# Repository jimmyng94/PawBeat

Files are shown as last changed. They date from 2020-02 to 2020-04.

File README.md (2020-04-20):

# PawPulse
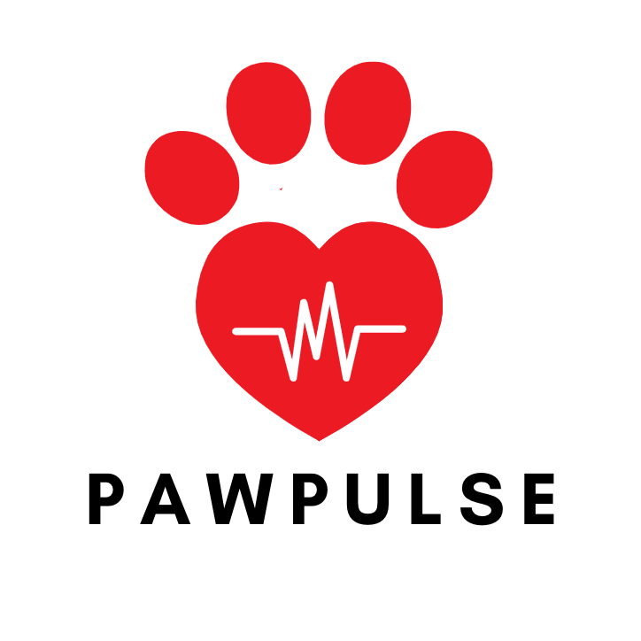
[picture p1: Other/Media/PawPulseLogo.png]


PawPulse is an [open-source](https://github.com/jimmyng94/PawPulse/blob/master/LICENSE) pet health monitoring project developed by Engineering MSc students at the University Of Glasgow using a Raspberry Pi. The main functions that the project provide are:
- Heartbeat Monitoring
- Pedometer
- Live data display through a [website](https://tymonherzyk.github.io/PawPulseWeb/)

Currently, the development of the project is only intended for use on a dog. Usage on other pets will require further testing.

## Project Architecture
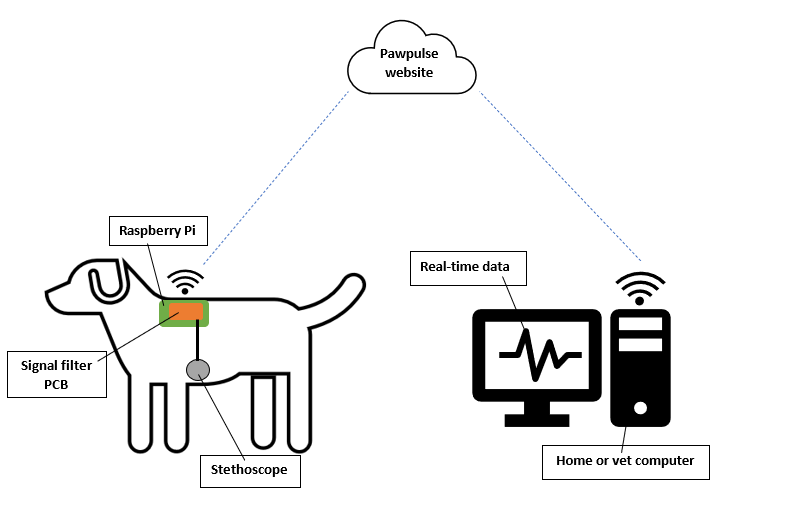
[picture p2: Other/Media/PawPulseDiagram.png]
Basic Design

#### Hardware
All the sensors along with the raspberry will be attached to a dog harness to collect and process the data before posting the data to the web page. Therefore, the PCB is split into 2 individual boards. The 1st board is a PiHat where the [IMU](https://www.st.com/resource/en/datasheet/lsm6ds3.pdf) is located. The 2nd board contains the [ADC](http://www.ti.com/lit/ds/symlink/ads1015.pdf) and is located beside the microphone. Both boards are using I2C to communicate with the Raspberry Pi.

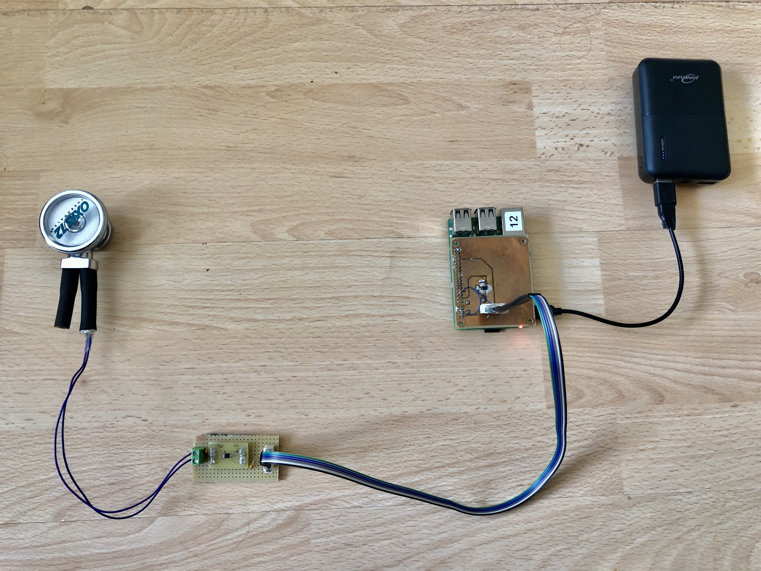
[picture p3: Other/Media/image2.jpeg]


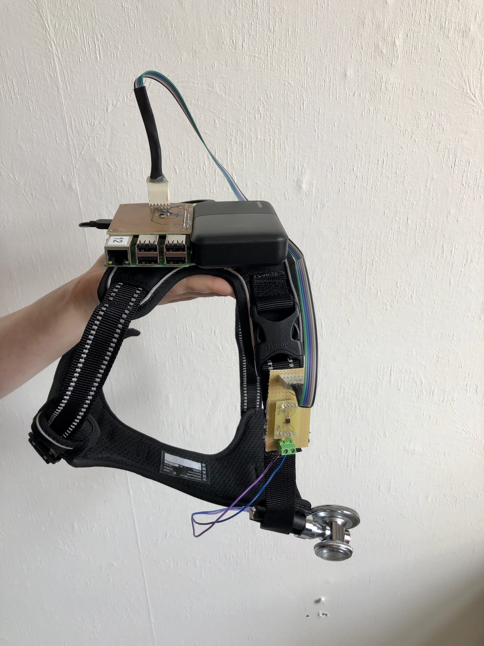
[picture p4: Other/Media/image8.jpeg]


#### Software
The PawPulse software is split into two main files **pawpulse.cpp** and **pawpulseWebClient.cpp**. The pawpulse file is responsible for aquiring data for the dog's heartbeat and step count from the corresponding hardware. Once the data has been aquired through the getBPM() and getStep() functions it is then passed to the writeBPM() and writeSTEP() functions. These functions sort the data into the correct JSON format and pass it to the pawpulseWebClient.cpp file through named pipes bpm_fifo and step_fifo. The pawpulseWebClient file is responsible for uploading the data to the PawPulse website through the PubNub API. Threading has been used throughout the software to allow both processes (bpm and step) to work at the same time.  

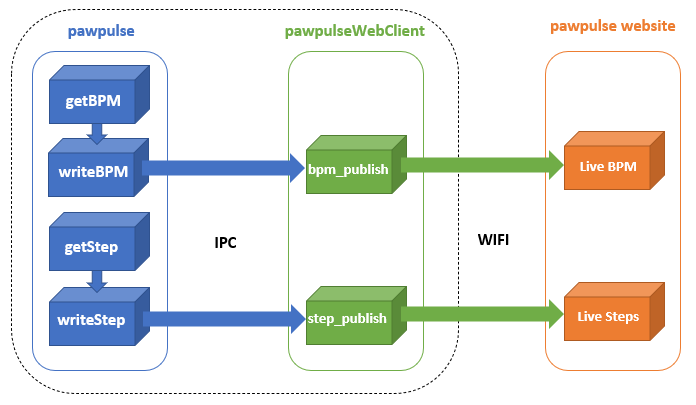
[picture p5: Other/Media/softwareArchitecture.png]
Software Architecture


#### Website
A website has been built in order to test the web capabilities of this project. The website has been designed to function as a profesional space in which the data from the PawPulse system can be displayed to users in real-time. The website has been built using HTML, CSS and JavaScript languages. To display data in real-time it utlises libraries such as PubNub API and EON. The website has also been built to be responsive and hence can be viewed safely on phone and monitors. Example screenshots from the "Live Data" page are given below:

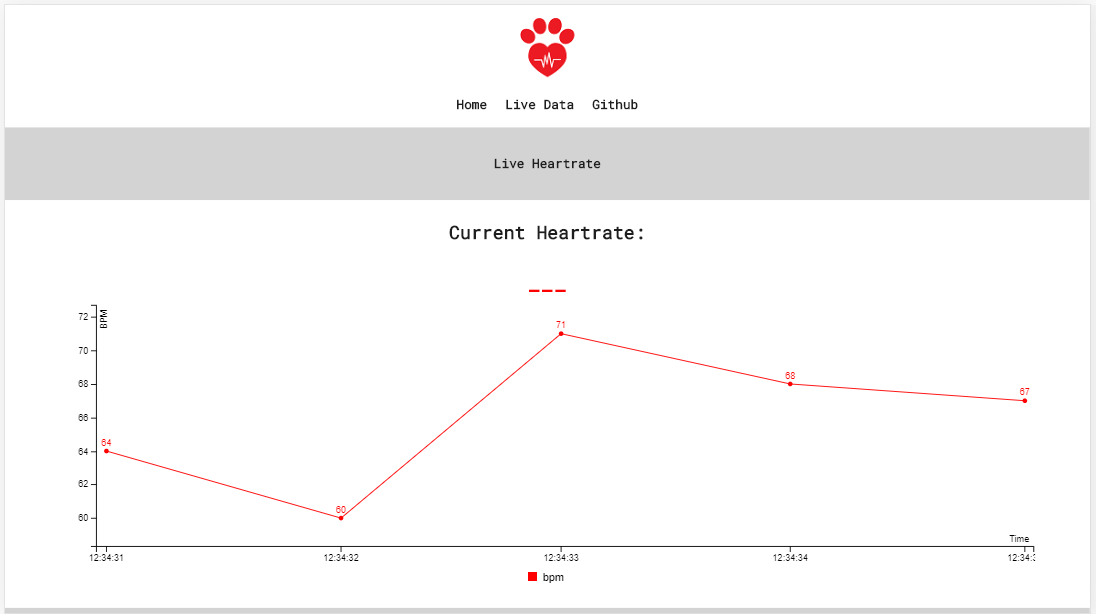
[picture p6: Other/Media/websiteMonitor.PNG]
Web Monitor


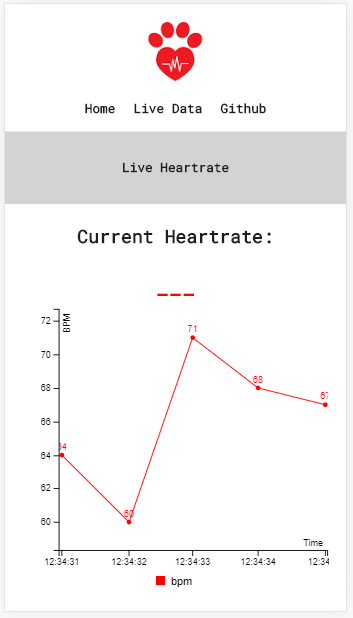
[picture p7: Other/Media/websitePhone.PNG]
Web Phone


The PawPulse website is hosted at https://tymonherzyk.github.io/PawPulseWeb/

#### Guides
Further information as well as in-depth installation and development guides for this project can be found on our Github [Wiki](https://github.com/jimmyng94/PawPulse/wiki) Page.

## Quick Installation
A full in-depth installation guide is available in our [wiki](https://github.com/jimmyng94/PawPulse/wiki/Installation-Guide).

#### 1. Clone PawPulse github repository
On the main repository page, click the green "Clone or Download" button, copy the address that drops down. In your chosen directory clone the PawPulse repository by running the folowing code:
```
git clone *copied address*
```
#### 2. Install required libraries
Install the required libraries (see the wiki for more information):
* ADS1015 Library
* LSM6DS3 Library
* Fir1 Library
* PubNub c-core
* WiringPi

#### 3. Make the pawpulse.cpp executable
To make the pawpulse executable file navigate into the "Software" folder and use the "CMakeLists.txt" file. This is done by running the following code:
```
cmake .
make
```
A new executable with the name **pawpulse** should now be available in the "Software" folder.

#### 4. Make the pawpulseWebClient.cpp executable
To make the pawpulseWebClient executable file navigate into the "Software" folder and use the "pawpulseWebClient.mk" makefile. This is done by running the following code:
```
make -f pawpulseWebClient.mk
```
A new executable with the name **pawpulseWebClient** should now be available in the "Software" folder.

#### 5. Run software
To run both executables simply run the following code in the "Software" folder using two seprate command lines:
```
./pawpulseWebClient
```
```
./pawpulse
```
## Additional Functionality
Recommendations of possible functions that could be added in the future: 
- Automated execution of the PawPulse software.
- Live heartbeat playback allowing the owner to hear their pet's heartbeat and make it more convenient for a veterinarian to monitor pets
- GPS tracking
- Health diagnoses and recommendations
- Personalised website login
- Phone application development for convenience

## Demonstration
A demonstration of the real-time application and operation of the PawPulse software is available on the PawPulse [Youtube Channel](https://www.youtube.com/channel/UC-eADsYPdyjXFOSjoH-YVWg). The demonstration shows the software being executed and the data being uploaded to the PawPulse website in real-time.

Video Link - https://www.youtube.com/watch?v=mI9MpOQwHOM

## Social Media
- [Instagram](https://www.instagram.com/paw_pulse/)
- [Youtube](https://www.youtube.com/channel/UC-eADsYPdyjXFOSjoH-YVWg)
- [Twitter](https://twitter.com/paw_pulse)

## Authors 
- [Maggie Wood](https://github.com/maggwood) - Data acquisition and data filtering
- [Ng Jing Ming](https://github.com/jimmyng94) - Hardware and hardware/software communication
- [Tymon Herzyk](https://github.com/tymonherzyk) - IPC, web client and website

## Disclaimer
Disruption due to COVID-19 has prohibited us from running any actual tests on our test dog. Thus, this project is not guaranteed to work on a dog. Testing was only done using a human heartbeat that was collected before the disruption. In the future we hope to be able to test it on a real pet and collect more data to improve our algorithm. Thank you for your understanding.

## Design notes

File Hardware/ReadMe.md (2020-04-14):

# Hardware
Hardware development of this project went through a few development and testing to determine the best circuit used for this project. 
This project requires an analog to digital converter to convert the analog microphone signal and an inertial measurement unit for pedometer function. 
The selected component used for version 1 of this project is listed below.
The schematic, board design and PCB mask are included in the newest version.  

## Version 0 (Concept)
- Mic signal is passed through a 4th order Low pass filter that filters noise above 1kHz. Used a [LM324N](http://www.ti.com/lit/ds/symlink/lm324-n.pdf). All the components are located in MicBOB_V0. 
- The IMU selected is attached on a PiHat. Fairly straight forward
###### Problems
- The Low pass filter seems to be attenuating the signal and no signal reaches the ADC.
- Missing power line to the VCC of the IMU.

## Version 1 (Prototype A)
- Removed the Low Pass Filter and used the ADS1014 Programmable Gain Amplifier(PGA) to amplify the signal from the microphone.
- Added a diode for reverse voltage protection.
- Added a trace to supply power to the IMU.

| Part | Quantity|
|-----| :-----: |
|Raspberry Pi | 1|
|[ADC ADS1014](http://www.ti.com/lit/ds/symlink/ads1015.pdf)|1|
|[IMU LSM6DS3](https://www.st.com/resource/en/datasheet/lsm6ds3.pdf)|1|
|6mm Microphone|1|
|1206 0.1uf Capacitor |2|
|5K Resistor|4|
|1N4148 Diode|1|
|20-pin Female Header|1|
|6-way header Molex connector|2|
|6-way shell Molex connector|2|
|M2.5 Standoffs	|4|
|M2.5 Screws	|4|

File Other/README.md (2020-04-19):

# Other
This folder contains files that do not fall under the category of hardware or software. 

## Folders
#### Initial Presentation
This folder contains the powerpoint slides used during the initial presentation given at the University of Glasgow on the 29/01/2020.

#### Media
This folder contains all the media files used on the PawPulse github.

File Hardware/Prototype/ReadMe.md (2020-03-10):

# Hardware Development
* After some consideration of device that are suitable for this project there are the ADS1014 is selected and the LSM6DS3 is selected. 
* To test the ADC a breakoutboard (msop10.brd) is develop for quick testing.
* The IMU used for initial testing is purchased from [sparkfun](https://www.sparkfun.com/products/13339)

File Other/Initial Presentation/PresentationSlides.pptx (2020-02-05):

## Development of health monitoring system for dogs (PawPulse)

Team 12
Jing Ming Ng
Margaret Wood
Tymon Herzyk

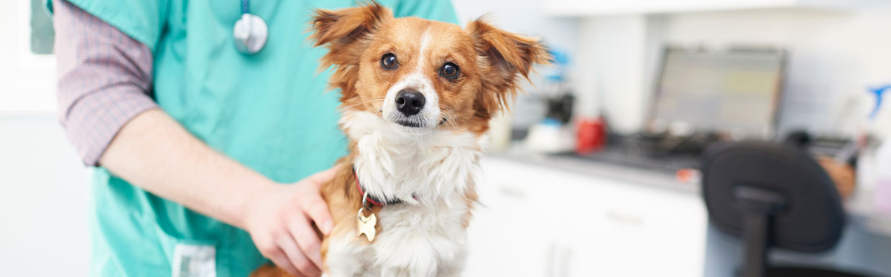
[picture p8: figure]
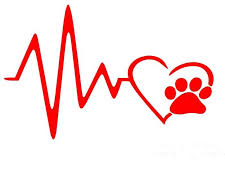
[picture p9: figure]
A picture containing drawing Description generated with very high confidence

## Market & opportunity

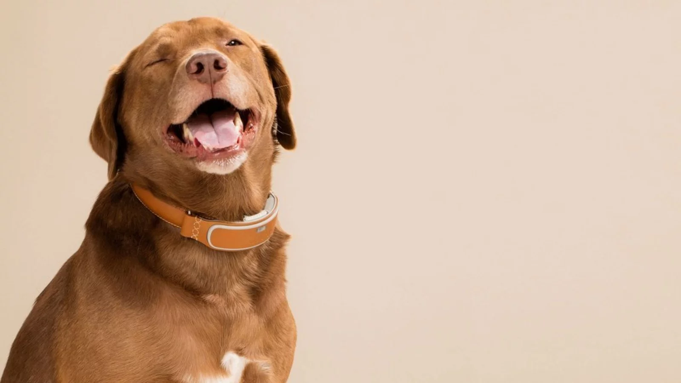
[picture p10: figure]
A brown and white dog looking at the camera Description generated with very high confidence
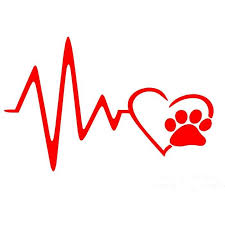
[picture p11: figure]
A picture containing drawing Description generated with very high confidence

Competitors

- Most do trackers do not track heartbeat.
- Trackers with heartbeat have large costs associated.
- Readings are not accurate.
- Low customer reviews.

Innovation

- Inclusion of heartbeat sensing capabilities.
- Low-cost design.
- Ubiquitously available production methods.
- Open-source design

31%
of owners don't know the weight or body condition of their dog (PDSA 2019)

15%
of UK dogs will suffer from a heart condition during their life. (Vet's Kitchen 2020)

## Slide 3

Our Plan

Social Media

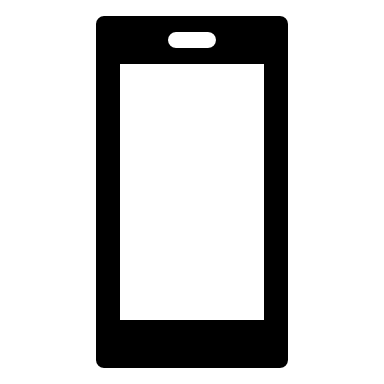
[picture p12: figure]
Smart Phone

Follow @paw_pulse on Twitter and Instagram for #pupdates!

Device

Next Steps

- How heartrate will be measured?
- Total number of features other than heart rate?
- How will device attach to dog?

Hardware Design

- Sensors and Raspberry Pi mounted to wearable apparatus
- Small and compact
- Battery Pack

Real Time Processing

- Intake animal's heartbeat, step count, etc. from sensors
- DSP of sensor signals
- Display useful information thru web page interface
- Data logged for future retrieval

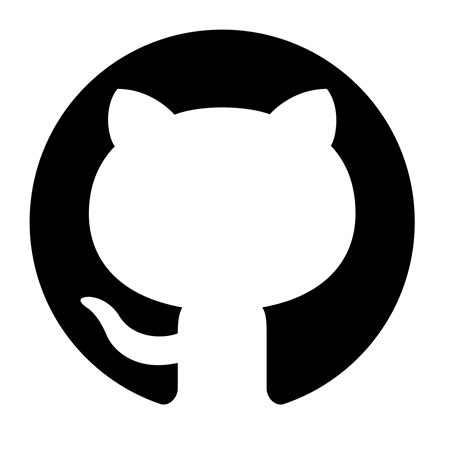
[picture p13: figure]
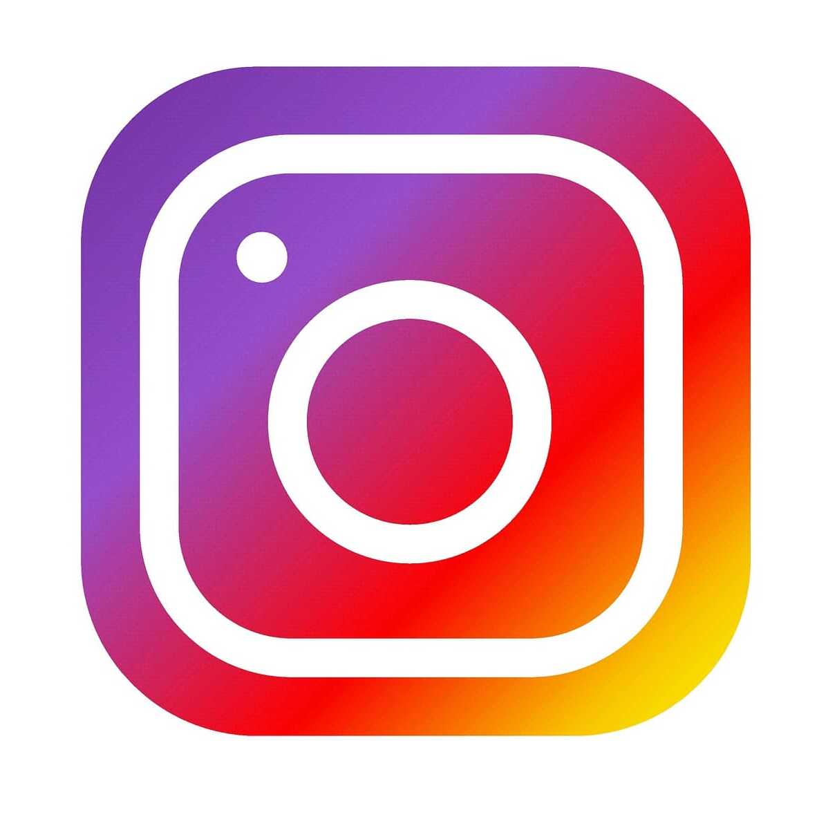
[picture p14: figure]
A picture containing drawing Description generated with very high confidence
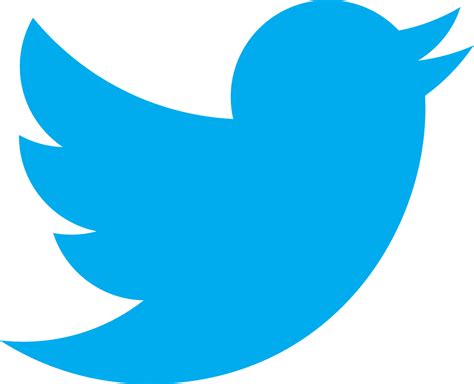
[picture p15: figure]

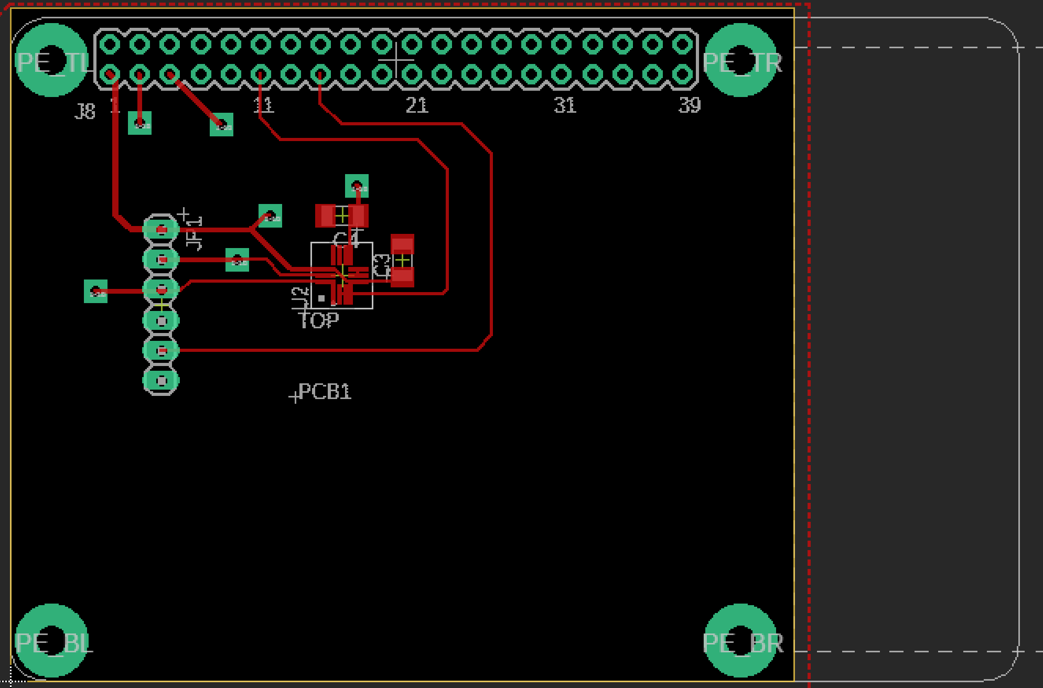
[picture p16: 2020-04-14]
Hardware/V1/piHatV1/pihat.PNG

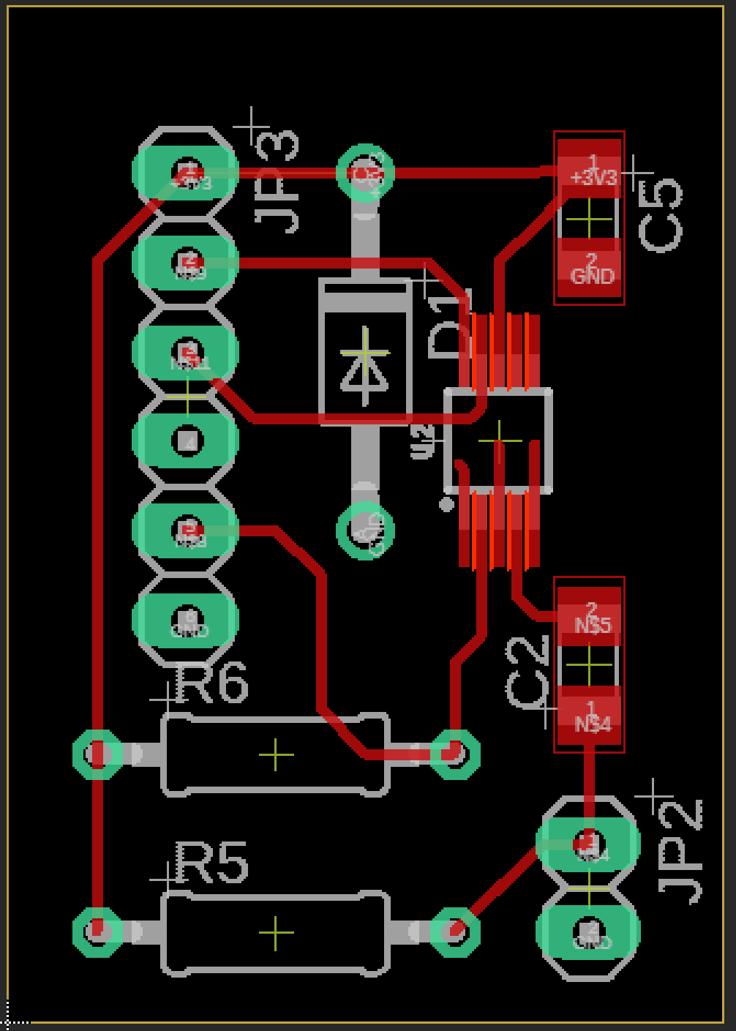
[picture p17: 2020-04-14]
Hardware/V1/mic_bobV1/mic_bobV1.PNG

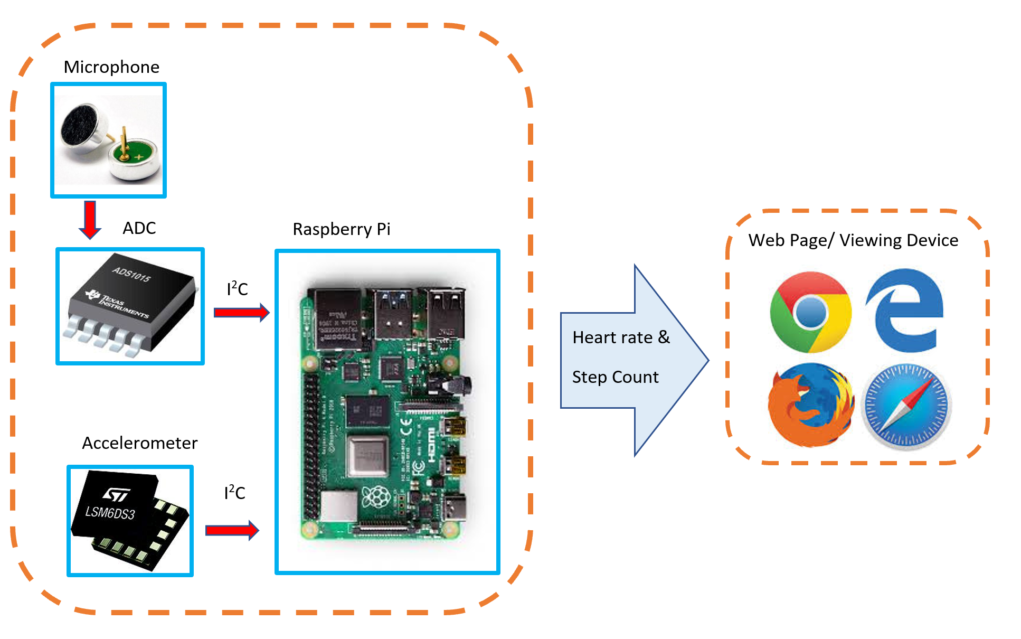
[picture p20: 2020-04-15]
Other/Media/flowDiagram.png

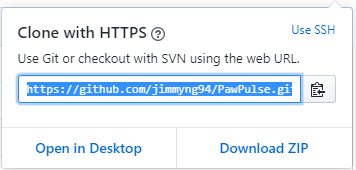
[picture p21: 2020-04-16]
Other/Media/githubLink.PNG

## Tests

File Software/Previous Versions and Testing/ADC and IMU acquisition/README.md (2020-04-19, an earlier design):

# Threaded Data collection With interrupt

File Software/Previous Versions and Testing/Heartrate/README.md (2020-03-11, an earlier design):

# Heart Rate Processing using Microphone output through ADS 1014 

## Requirements
* [WiringPi](http://wiringpi.com/)
* [Fir1 Package](https://github.com/berndporr/fir1)

## Install
```
cmake .
make
sudo make install
sudo ldconfig
```

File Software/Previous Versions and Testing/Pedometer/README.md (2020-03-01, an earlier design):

# LSM6DS3 RaspberryPI C++ Library

## Requirement
* [WiringPi](http://wiringpi.com/)

## Install
```
cmake .
make
sudo make install
sudo ldconfig
```

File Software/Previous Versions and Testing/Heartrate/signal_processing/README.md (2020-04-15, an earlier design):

Run coefficient_generator.py

Run processing.cpp

REQUIRES: Fir1 - Bernd Porr https://github.com/berndporr/fir1, ADS1015, LSM6DS3

What's needed: 

- Add code for sending bpm & step down pipe (not sure if these variables even send from the right place...)              
              
- Not sure of best threshold for bpm conversion with 50 sps - would need new samples in Excel to examine
               
- Not sure of threshold for step - I just made something up. Any way there is some data I could look at?
               
- Not sure which pin ACC interrupts from. Needed for #define statement
               
I have no idea if any of this will work

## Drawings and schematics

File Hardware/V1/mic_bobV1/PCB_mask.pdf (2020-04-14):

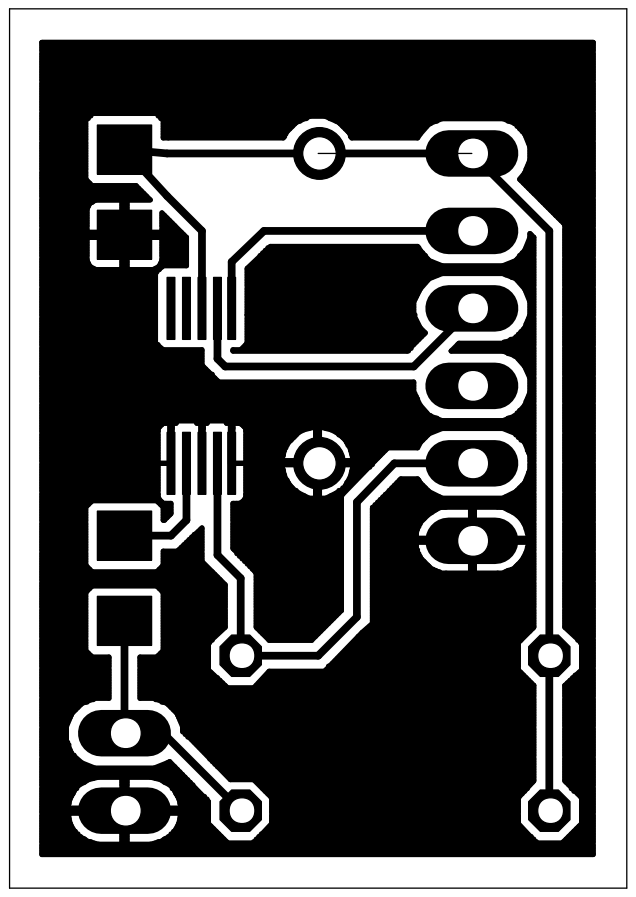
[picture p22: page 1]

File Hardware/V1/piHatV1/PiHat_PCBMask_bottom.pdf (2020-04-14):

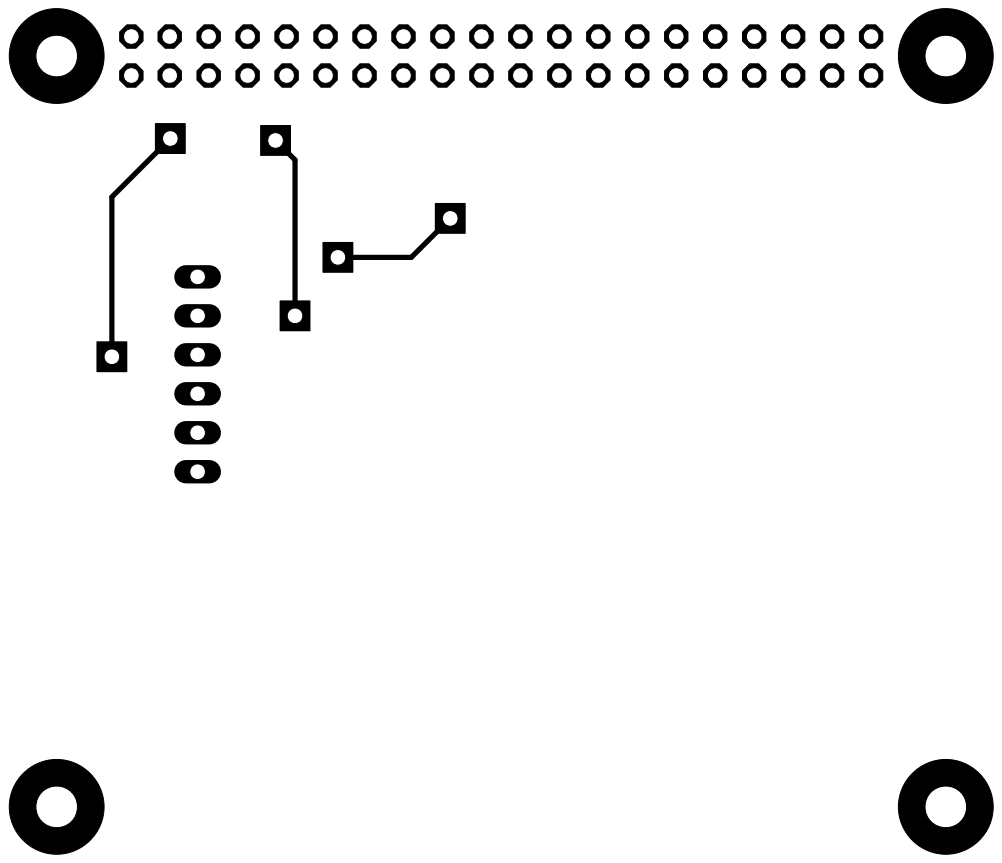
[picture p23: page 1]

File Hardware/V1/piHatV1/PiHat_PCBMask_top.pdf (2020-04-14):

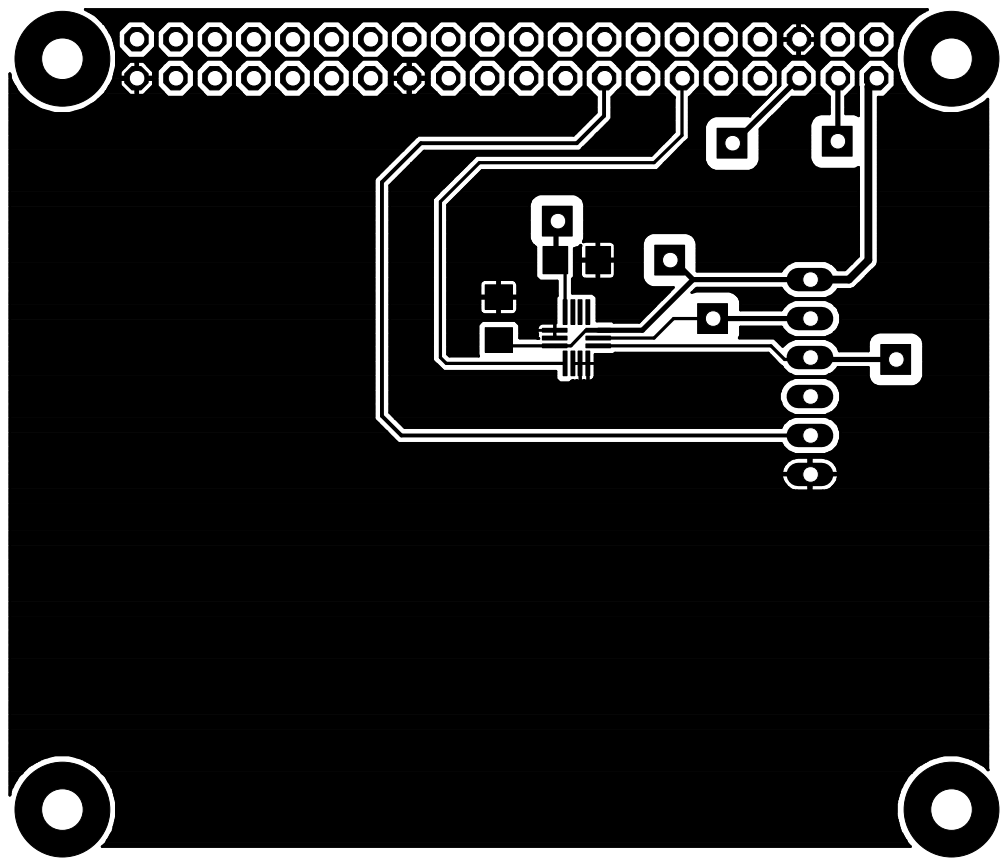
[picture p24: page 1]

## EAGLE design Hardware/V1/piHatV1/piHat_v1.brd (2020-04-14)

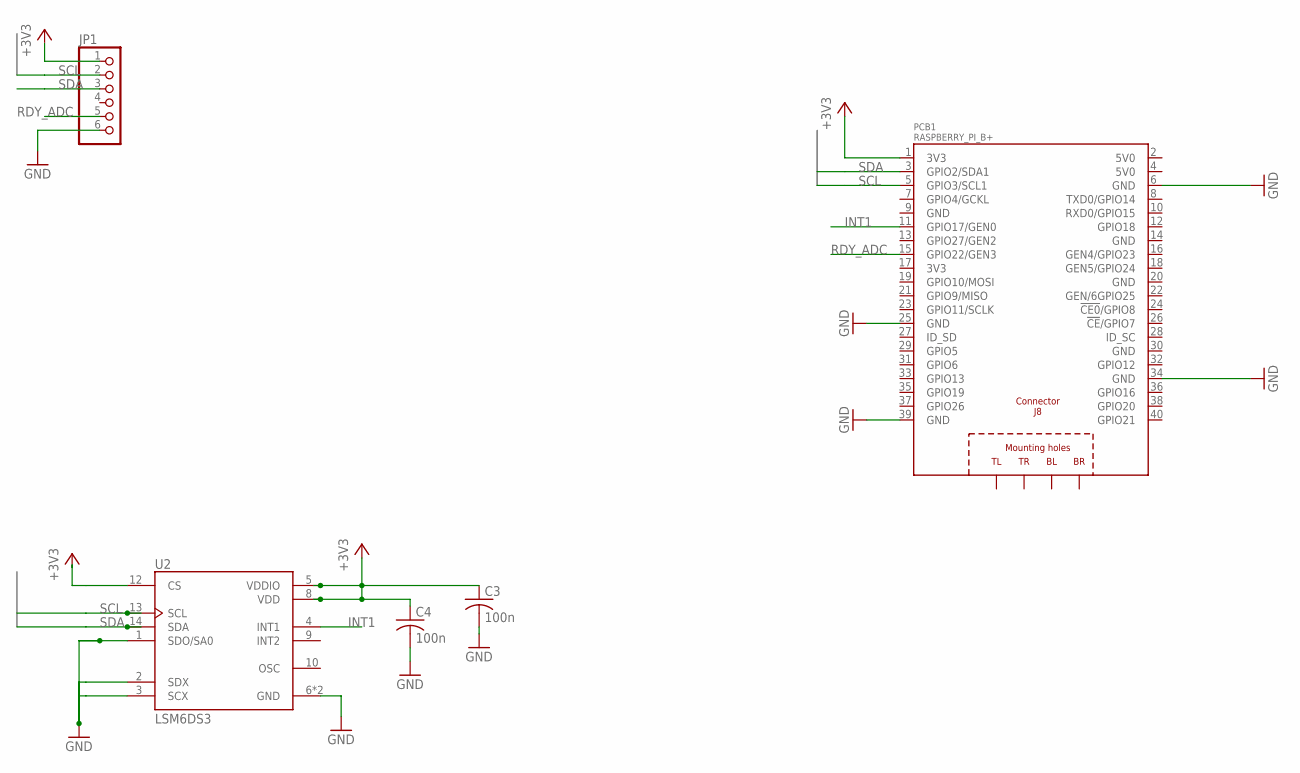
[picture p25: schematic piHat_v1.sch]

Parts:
C3, C4: 100n; C1206
JP1: PINHD-1X6; 1X06
PCB1: RASPBERRY_PI_B+
U2: LSM6DS3; PQFN50P300X250X86-14N

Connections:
+3V3: C3.1, C4.1, JP1.1, PCB1.1 (3V3), U2.5 (VDDIO), U2.8 (VDD), U2.12 (CS)
GND: C3.2, C4.2, JP1.6, PCB1.6 (GND), PCB1.25 (GND), PCB1.39 (GND), U2.1 (SDO/SA0), U2.2 (SDX), U2.3 (SCX), U2.6 (GND), U2.7 (GND)
GND@7: PCB1.34 (GND)
INT1: PCB1.11 (GPIO17/GEN0), U2.4 (INT1)
RDY_ADC: JP1.5, PCB1.15 (GPIO22/GEN3)
SCL: JP1.2, PCB1.5 (GPIO3/SCL1), U2.13 (SCL)
SDA: JP1.3, PCB1.3 (GPIO2/SDA1), U2.14 (SDA)

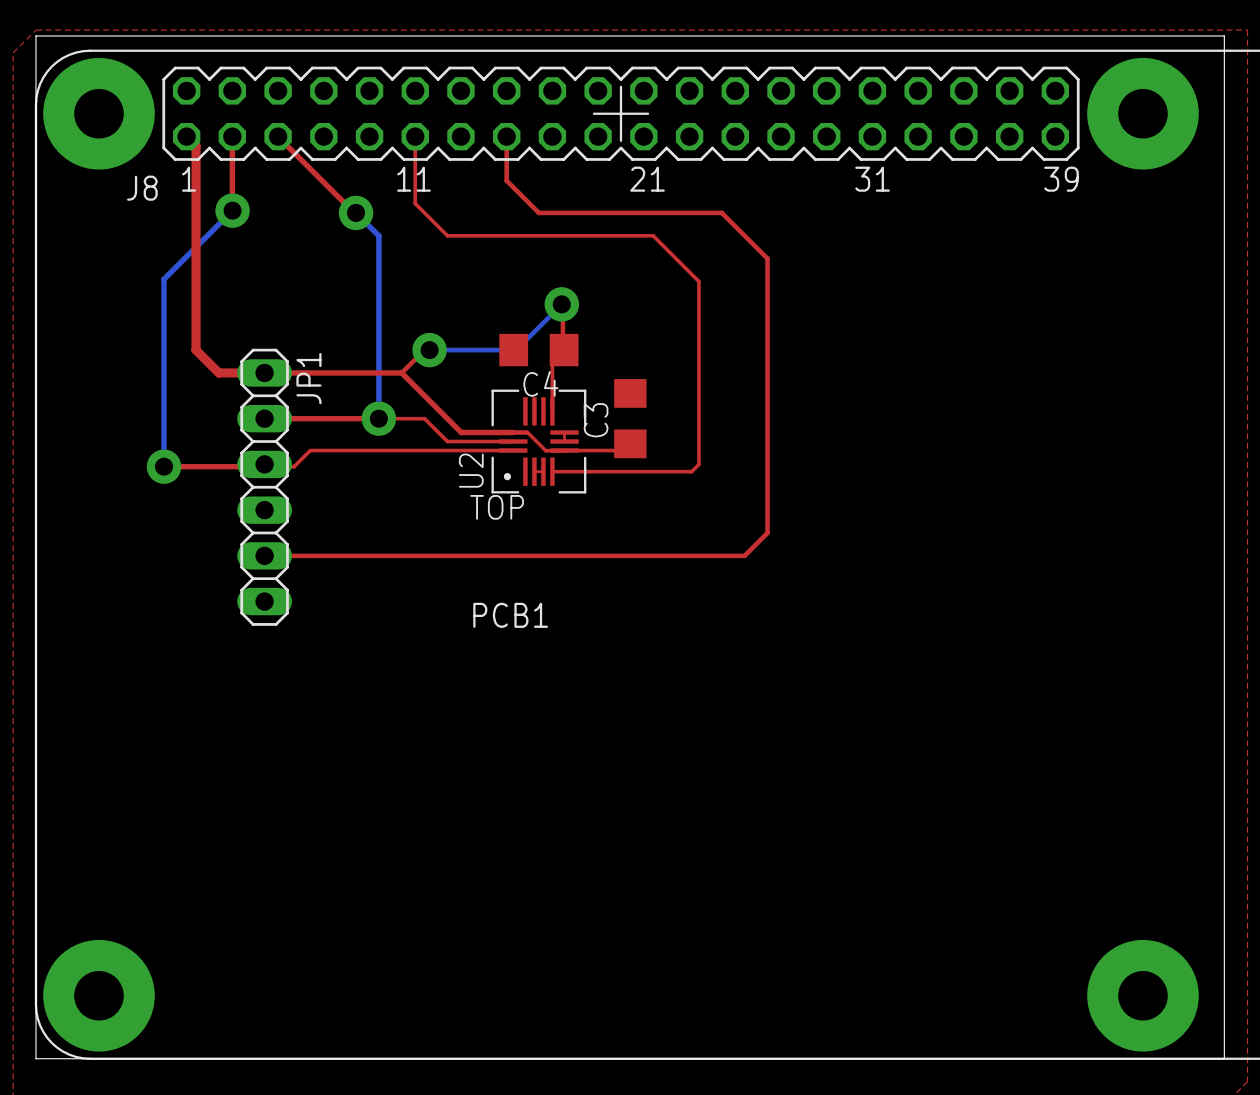
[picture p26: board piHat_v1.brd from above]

Board: 2 copper layers, 66.0 x 56.8 mm, 5 parts (0 on the bottom side), 6 nets.

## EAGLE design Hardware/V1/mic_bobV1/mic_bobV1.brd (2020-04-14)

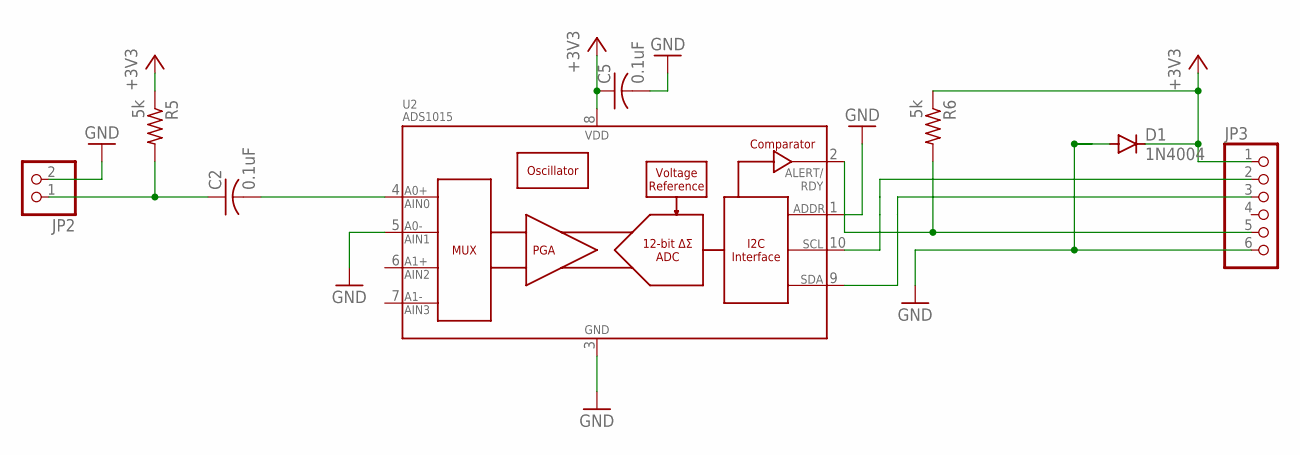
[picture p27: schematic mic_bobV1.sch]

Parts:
C2, C5: 0.1uF; C1206
D1: 1N4004; DO41-10
JP2: PINHD-1X2; 1X02
JP3: PINHD-1X6; 1X06
R5, R6: 5k; 0207/10
U2: ADS1015; MSOP10

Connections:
+3V3: C5.1, D1.C, JP3.1, R5.1, R6.1, U2.8 (VDD)
GND: C5.2, D1.A, JP2.2, JP3.6, U2.1 (ADDR), U2.3 (VSS), U2.5 (AIN1)
unnamed: C2.1, JP2.1, R5.2
unnamed: C2.2, U2.4 (AIN0)
unnamed: JP3.5, R6.2, U2.2 (ALERT/RDY)
unnamed: JP3.2, U2.10 (SCL)
unnamed: JP3.3, U2.9 (SDA)

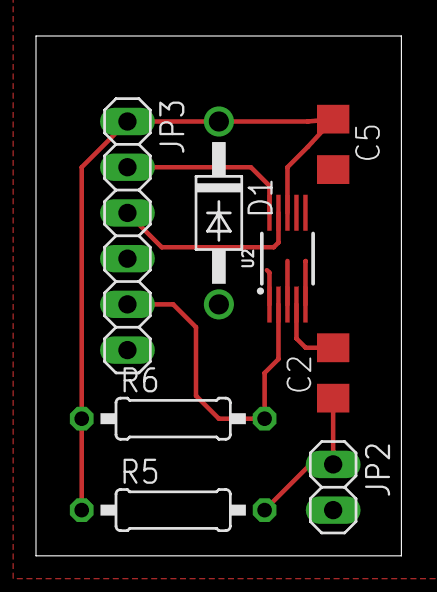
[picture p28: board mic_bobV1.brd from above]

Board: 2 copper layers, 20.3 x 28.9 mm, 8 parts (0 on the bottom side), 7 nets.

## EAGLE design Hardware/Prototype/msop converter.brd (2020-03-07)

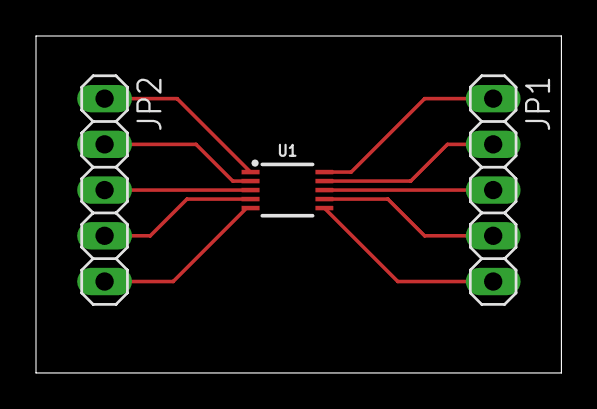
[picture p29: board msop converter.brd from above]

Board: 2 copper layers, 29.2 x 18.7 mm, 3 parts (0 on the bottom side), 10 nets.

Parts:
JP1, JP2: 1X05
U1: ADS1015; MSOP10

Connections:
unnamed: JP2.1, U1.1
unnamed: JP2.2, U1.2
unnamed: JP2.3, U1.3
unnamed: JP2.4, U1.4
unnamed: JP2.5, U1.5
unnamed: JP1.1, U1.10
unnamed: JP1.2, U1.9
unnamed: JP1.3, U1.8
unnamed: JP1.4, U1.7
unnamed: JP1.5, U1.6

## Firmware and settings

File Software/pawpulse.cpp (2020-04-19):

#include <iostream> 
#include <fstream> 
#include <fcntl.h> 
#include <inttypes.h>
#include <linux/i2c-dev.h> 
#include <stdio.h> 
#include <unistd.h> 
#include <stdlib.h> 
#include <sys/types.h> 
#include <sys/stat.h> 
#include <sys/ioctl.h> 
#include <wiringPi.h> 
#include <wiringPiI2C.h> 
#include <errno.h> 
#include <ADS1015.h> 
#include <vector> 
#include <cmath> 
#include <time.h> 
#include "LSM6DS3.h"
#include "Fir1.h"
#include <string.h> 
#include <thread>
#include <sstream>
#define ADC_PIN 3	//input pin for ADC for microphone
#define ACC_PIN 7	//input pin for accelerometer
#define Fs 120		//sampling frequency of ADC

using namespace std; 
bool simulate = true;
static volatile int step = 0;
static volatile int counter = 0; 
static volatile int upflag = 0;
static volatile int stepflag = 0;
static volatile int t = 0;
vector <float> _bpm;
vector <float> _step;
std::vector<int> arr;	//handles simulated adc data
std::vector<float> acc_x;	//handles simulated acc data
std::vector<float> acc_y;
std::vector<float> acc_z;
static volatile bool threadRunning ;

//set up hardware
Adafruit_ADS1015 ads; 
LSM6DS3 imu(I2C_MODE, 0x6A);

//set up fir filter
Fir1 fir("hr_coeff.dat");

void getStep(void){
	float x;
	float y;
	float z;
	
	//if simulate is false, get next available value of x, y, and z from accelerometer
	if(simulate == false){
		x = imu.readFloatAccelX();
		y = imu.readFloatAccelY();
		z = imu.readFloatAccelZ();
	}
	//if simulate is true, get next available value of x, y, and z from pre-recorded data
	else{
		if (acc_x.empty() == false){ 
			x = acc_x.back();
			acc_x.pop_back(); 
			
			y = acc_y.back();
			acc_y.pop_back();
			
			z = acc_z.back();
			acc_z.pop_back();
		}
	}
	//calculate magnitude of x, y, and z to determine if a step has occurred (peak)
	float mag = sqrt(pow(x,2)+pow(y,2)+pow(z,2));
	//if peak occurs, add one to step count
	if(mag > 1.2){
		if(stepflag == 0){
			step++;
			_step.push_back(step);
			cout << "STEP: " << step << endl;
		}
		stepflag  = 5;
	}
	else{
		if(stepflag > 0){
			stepflag--;
		}
	}
	
}//end getStep

void getBPM(void){
	float val;
	//if simulate is false, get next available microphone readout from ADS
	if (simulate == false){ 
		val = ads.getLastConversionResults();  
	}
	//if simulate is true, get next available microphone readout from pre-recorded data
	else
	{	
		if (arr.empty() == false){ 
			val = arr.back();
			arr.pop_back(); 
		}
	}
	//put value through FIR filter to remove noise
	float newVal = fir.filter(val);
	int bpm = 0;
	//square values to remove negative numbers and to make peaks in data more apparent
	newVal = pow(newVal,2);
	//if peak occurs, identify time since last peak and use sampling frequency to calculate BPM
	if(newVal > 300){
		if(upflag == 0){
			if(t > 0){
				float new_bpm = 120.0/t*60.0;
				if(new_bpm > 30){
					bpm = new_bpm;
					_bpm.push_back(bpm);
				}
				cout << "BPM: " << bpm << endl;
			}
		t = 1;
		}
    upflag = 60;
	}
	else{
		if(upflag > 0){
		upflag--;
		}
	}
	t++;
}//end getBPM

void writeBPM(){
    int fd; 
    const char* bpmMsg; 
    const char* bpm_fifo = "bpm_fifo"; 
    mkfifo(bpm_fifo, 0666);
    while(_bpm.size() != 0) {
		auto bpm = _bpm.back();
		_bpm.pop_back(); 
		ostringstream bpmMsg_oss;
		bpmMsg_oss << "{\"eon\":{\"bpm\":" << bpm << "}}";
		string bpmMsg_s = bpmMsg_oss.str();
		bpmMsg = bpmMsg_s.c_str();
		fd = open(bpm_fifo, O_WRONLY); 
		if (fd==-1) {
			perror("open error");
		}
		if (write(fd, bpmMsg, sizeof(bpmMsg_s))==-1) {
			perror("write error");
		}
		else {
			printf("Message written: %s \n", bpmMsg);
		}
		close(fd); 
    }
}//end writeBPM

void writeStep(){
    int fd; 
    const char* stepMsg; 
    const char* step_fifo = "step_fifo"; 
    mkfifo(step_fifo, 0666);
    while(_step.size() != 0) {
		auto step = _step.back();
		_step.pop_back(); 
		ostringstream stepMsg_oss;
		stepMsg_oss << "{\"eon\":{\"steps\":" << step << "}}";
		string stepMsg_s = stepMsg_oss.str();
		stepMsg = stepMsg_s.c_str();
		fd = open(step_fifo, O_WRONLY); 
		if (fd==-1) {
			perror("open error");
		}
		
		if (write(fd, stepMsg, sizeof(stepMsg_s))==-1) {
			perror("write error");
		}
		else {
			printf("Message written: %s \n", stepMsg);
		}
			close(fd); 
    }
}//end writeStep


void sendBPM(){
	threadRunning  = true;
	std::thread sendBPM(writeBPM); 
	sendBPM.join(); 
	threadRunning  = false;
 }
 
void sendStep(){
	threadRunning  = true;
	std::thread sendStep(writeStep); 
	sendStep.join(); 
	threadRunning  = false;
 }
 
void startBPM(){
	std::thread th0(getBPM);
	th0.join();
}

void startStep(){
	std::thread th1(getStep);
	th1.join();
}

int main (int,char**)
{
	fir.reset ();
	
	//If the code is being processed in real-time, the value of simulation will be false. This will enable the programme to use an
	//interrupt to determine when new values are available from the ADS.
	if (simulate == false){
		wiringPiSetup(); 
		pinMode(ADC_PIN, INPUT);
		//set up ADS
		ads.begin(); 
		ads.setGain(GAIN_FOUR);
		ads.startComparator_SingleEnded(0, 1000);
		
		//If-statement to determine if the accelerometer is able to be read
		if (imu.begin() != 0) 
		{ 
			std::cout << "Problem starting the sensor at 0x6A." << std::endl; 
			return 1;
		} 
		else 
		{ 
			std::cout << "Sensor at 0x6A started." << std::endl; 
			imu.settings.gyroEnabled =0; 
			imu.settings.accelRange = 2;  //Max G force readable.  Can be: 2, 4, 8, 16
			imu.settings.accelSampleRate = 26; //Hz.  Can be: 13, 26, 52, 104, 208, 416, 833, 1666, 3332, 6664, 13330
		}  
		
		//Interrupt when ADS gets new reading
		if(wiringPiISR(ADC_PIN, INT_EDGE_RISING, &startBPM) > 0){ 
			cout << "INTERRUPT!" << endl; 
		}
	}//end if
	
	//If simulate is true, this means that new values will be coming in from pre-recorded data in a file. The ADS has one data file,
	//while the accelerometer has three data files, one for each of the x, y, and z channels of its gyroscope
	else{
		//Create array for sending simulated heartbeat data to getBPM function
		std::ifstream arr_handler("ads_120_C.txt");
		// using a std::vector to items.  It handles memory allocation automatically.
		float number;
		while (arr_handler>>number) {
			arr.push_back(number);
			// ignore anything else on the line
			arr_handler.ignore(std::numeric_limits<std::streamsize>::max(), '\n');
		}
		
		//Create 3 arrays for sending simulated step data to getStep function
		std::ifstream accx_handler("3x.txt");
		while (accx_handler>>number) {
			//cout<< typeid(number).name() << endl;
			acc_x.push_back(number);
			// ignore anything else on the line
			accx_handler.ignore(std::numeric_limits<std::streamsize>::max(), '\n');
		}
		std::ifstream accy_handler("3y.txt");
		while (accy_handler>>number) {
			acc_y.push_back(number);
			// ignore anything else on the line
			accy_handler.ignore(std::numeric_limits<std::streamsize>::max(), '\n');
		}
		std::ifstream accz_handler("3Z.txt");
		while (accz_handler>>number) {
			acc_z.push_back(number);
			// ignore anything else on the line
			accz_handler.ignore(std::numeric_limits<std::streamsize>::max(), '\n');
		}
	
	//while loop to ensure that ADS and accelerometer arrays are both processed fully. It uses the usleep function to send samples
	//in the simulation at the rate they would normally be available from the ADS and accelerometer.
	int count = 0;		
	while (arr.empty() == false || acc_x.empty() == false){
		count++;
		// calling getBPM at ADS sampling frequency, 120sps
		int sleepTime = 1000000/120;
		usleep(sleepTime);
		if(arr.empty() == false){
			startBPM();
			sendBPM();
			
		}
		//Accelerometer samples at 26sps, which is ~1/5 of the frequency of the ADS. This means that for every 5 samples sent by
		//the ADS, one sample should be sent by the accelerometer.
		if(count == 5){ 
			startStep();
			sendStep();
			count = 0;
		}
	}//end while
	}//end else
	return 0;
 }//end main

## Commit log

2020-02-19 Update and rename mic2i2s to mic2i2c
    Added wiring pi library
2020-02-19 Create Prototype
2020-02-19 Update and rename Prototype to ReadMe
    correcting error
2020-02-19 Create Breakout board
2020-02-26 Update mic2i2c.cpp
    Reads data from ADC, in while loop
2020-02-27 Update SparkFunLSM6DS3.cpp
    revert back to to original with minimal change only to the i2c section
2020-03-04 Update mic2i2c.cpp
    Reads 12000 samples of voltage from microphone, stores in buffer, then prints values to file titled 'heartbeat_30'.
2020-03-07 Create PCB
2020-03-07 Add files via upload
    Used for testing ADS1014
    [msop converter.brd]
2020-03-07 Update and rename Breakout board to ReadMe.md
2020-03-11 Update LSM6DS3.cpp
    attempt to add interrupt pin 1
2020-03-13 Update Interrupt.cpp
    correcting file for mic
    [Interrupt.cpp]
2020-03-20 Update processing.cpp
    1st integration/ broken
    [processing.cpp]
2020-04-19 Rename ADC and IMU acquisition/CMakeLists.txt to Software/Previous Versions and Testing/ADC and IMU acquisition/CMakeLists.txt
2020-04-19 Update and rename ADC and IMU acquisition/readMe.md to Software/Previous Versions and Testing/ADC and IMU acquisition/README.md
2020-04-19 Rename ADC and IMU acquisition/threadedAccq.cpp to Software/Previous Versions and Testing/ADC and IMU acquisition/threadedAccq.cpp
2020-04-19 Rename ADC and IMU acquisition/imuDataLogger/CMakeLists.txt to Software/Previous Versions and Testing/ADC and IMU acquisition/imuDataLogger/CMakeLists.txt
2020-04-19 Rename ADC and IMU acquisition/imuDataLogger/imuAccq.cpp to Software/Previous Versions and Testing/ADC and IMU acquisition/imuDataLogger/imuAccq.cpp
2020-04-19 Rename ADC and IMU acquisition/imuDataLogger/Data_collected/3x.txt to Software/Previous Versions and Testing/ADC and IMU acquisition/imuDataLogger/Data_collected/3x.txt
2020-04-19 Rename ADC and IMU acquisition/imuDataLogger/Data_collected/3y.txt to Software/Previous Versions and Testing/ADC and IMU acquisition/imuDataLogger/Data_collected/3y.txt
2020-04-19 Rename ADC and IMU acquisition/imuDataLogger/Data_collected/3Z.txt to Software/Previous Versions and Testing/ADC and IMU acquisition/imuDataLogger/Data_collected/3Z.txt
2020-04-19 Rename ADC and IMU acquisition/imuDataLogger/Data_collected/0Z.txt to Software/Previous Versions and Testing/ADC and IMU acquisition/imuDataLogger/Data_collected/0Z.txt
2020-04-19 Rename ADC and IMU acquisition/imuDataLogger/Data_collected/0x.txt to Software/Previous Versions and Testing/ADC and IMU acquisition/imuDataLogger/Data_collected/0x.txt
2020-04-19 Rename ADC and IMU acquisition/imuDataLogger/Data_collected/0y.txt to Software/Previous Versions and Testing/ADC and IMU acquisition/imuDataLogger/Data_collected/0y.txt
2020-04-19 Rename ADC and IMU acquisition/imuDataLogger/Data_collected/1Z.txt to Software/Previous Versions and Testing/ADC and IMU acquisition/imuDataLogger/Data_collected/1Z.txt
2020-04-19 Rename ADC and IMU acquisition/imuDataLogger/Data_collected/1x.txt to Software/Previous Versions and Testing/ADC and IMU acquisition/imuDataLogger/Data_collected/1x.txt
2020-04-19 Rename ADC and IMU acquisition/imuDataLogger/Data_collected/1y.txt to Software/Previous Versions and Testing/ADC and IMU acquisition/imuDataLogger/Data_collected/1y.txt
2020-04-19 Rename ADC and IMU acquisition/imuDataLogger/Data_collected/2Z.txt to Software/Previous Versions and Testing/ADC and IMU acquisition/imuDataLogger/Data_collected/2Z.txt
2020-04-19 Rename ADC and IMU acquisition/imuDataLogger/Data_collected/2x.txt to Software/Previous Versions and Testing/ADC and IMU acquisition/imuDataLogger/Data_collected/2x.txt
2020-04-19 Rename ADC and IMU acquisition/imuDataLogger/Data_collected/2y.txt to Software/Previous Versions and Testing/ADC and IMU acquisition/imuDataLogger/Data_collected/2y.txt
2020-04-19 Rename heartrate/Examples/Interrupt.cpp to Software/Previous Versions and Testing/Heartrate/Examples/Interrupt.cpp
2020-04-19 Rename heartrate/signal_processing/filter.cpp to Software/Previous Versions and Testing/Heartrate/signal_processing/filter.cpp

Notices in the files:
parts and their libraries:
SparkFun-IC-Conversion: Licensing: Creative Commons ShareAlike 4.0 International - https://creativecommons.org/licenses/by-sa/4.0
